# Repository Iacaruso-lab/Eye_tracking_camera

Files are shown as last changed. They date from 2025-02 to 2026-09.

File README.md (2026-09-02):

Eye tracking camera

## Bill of materials

| Component | Quantity | Notes / Specifications |
| :--- | :---: | :--- |
| [PCB](https://jlcpcb.com/) | 1 | PCB thickness 0.4 - 0.6 mm |
| [Camera](https://www.aliexpress.com/item/32824666630.html?spm=a2g0o.order_list.order_list_main.4.20661802AZe992) | 1 | — |
| [SIL Connectors](https://cpc.farnell.com/harwin/d01-9972042/socket-sil-20way/dp/CN25209?mckv=sshopping_dc) | 2 | — |
| [Resistors](https://uk.rs-online.com/web/p/surface-mount-resistors/2413233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) | 3 | — |
| [IR LED](https://uk.rs-online.com/web/p/ir-leds/1847276?gb=s) | 3 | — |

## Assembly instructions

- Hold the PCB using tape on the thinner side
- Solder the IR LEDs in the following orientation (Polarity)
607056966-f32358ff-5b07-4499-b614-00222abcf55b

- Solder the resistors in the opposite side


- Solder the SIL connector


- Remove the SIL connector plastic part with clippers and cut the top excess of the SIL connector


- Strip off the camera cables


- Solder the camera wires with each corresponding pad and glue the camera with the PCB using super glue


- Solder the Vcc (3-3.3V), GND, and signal terminals with the cables

## Some notes

- The mass of the frame with the SIL conenctors is approximately 90 mg.


- In a second design iteration we added one degree of freedom to the 3D desing to allow for the camera orientation


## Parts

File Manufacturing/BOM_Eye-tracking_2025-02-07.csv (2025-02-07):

ID | Name | Designator | Footprint | Quantity | Manufacturer Part | Manufacturer | Supplier | Supplier Part | Price | Pins
1 | PAD | PTGND4,PTGND5,PTGND6,PTGND7,PTGND8,PTGND9 | PADPAD | 6 |  |  |  |  |  | 1
2 | PAD_SMD_3X1.5MM | U1,U2,U3 | PADPAD | 3 |  |  |  |  |  | 1
3 | 100Ω | R1,R2,R3 | R0402 | 3 | 0402WGF1000TCE | UNI-ROYAL(厚声) | LCSC | C25076 | 0.001 | 2
4 | LED0402[绿] | LED1,LED2,LED3 | LED0402-R-RD_GREEN | 3 | LED0402[绿] | null | LCSC | C9900022545 |  | 2

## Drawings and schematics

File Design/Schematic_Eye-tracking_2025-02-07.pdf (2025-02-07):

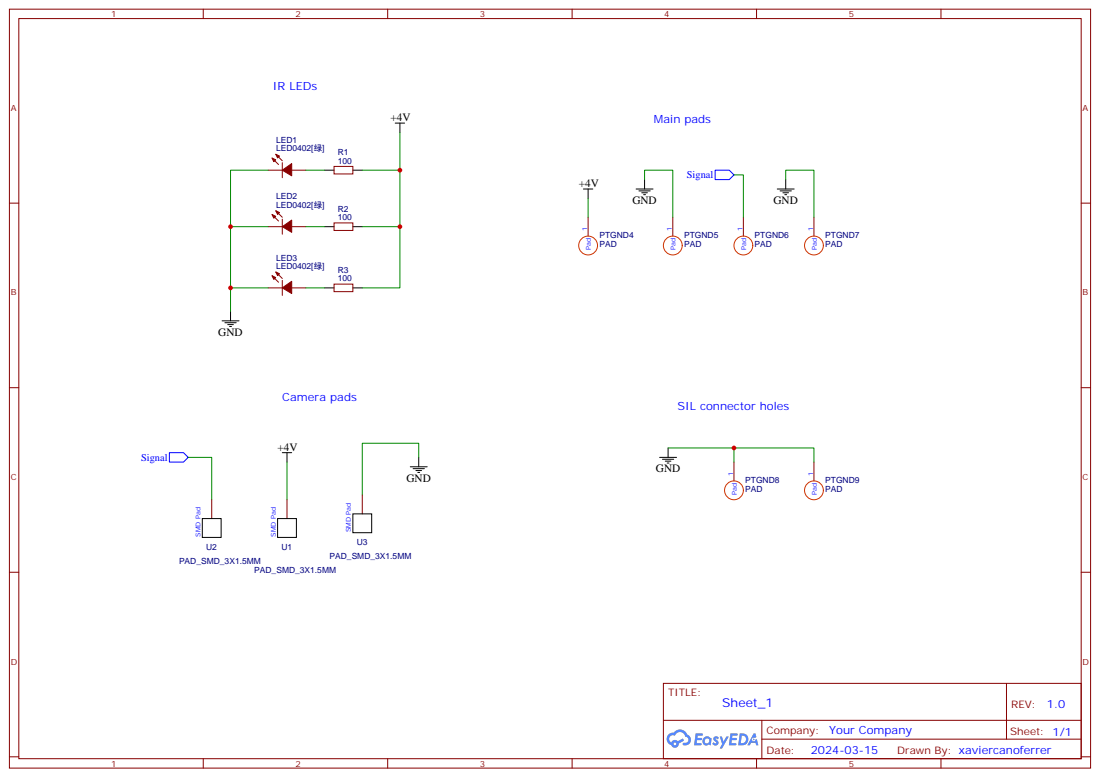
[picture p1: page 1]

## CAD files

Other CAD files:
Design/Apollo implant modified/Assembly PCB_1DOF.iam
Design/Apollo implant modified/Camera.ipt
Design/Apollo implant modified/Camera_holder_PCB_1DOF.ipt
Design/Apollo implant modified/NP2_Docking_PCB.ipt
Design/Apollo implant modified/NP2_Docking_PCB_1DOF.ipt
Design/Apollo implant modified/PCB_arm.ipt
Design/Apollo implant modified/SIL connector cut.ipt
Design/Apollo implant modified/SIL connector.ipt
Design/Apollo implant modified/camera_holder_SIL_socket_PCB.ipt
Design/Apollo implant modified/camera_holder_SIL_socket_v1.ipt
Design/Apollo implant modified/head.ipt
